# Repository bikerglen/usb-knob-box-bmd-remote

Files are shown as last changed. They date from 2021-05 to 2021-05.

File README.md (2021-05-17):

# usb-knob-box-bmd-remote

Blog post describing this project: https://bikerglen.com/blog/usb-knobs-that-double-as-a-blackmagic-remote/

If using the C# .NET app for testing, the product ID needs to be set to 0x0014 for the EFM8UB@ version or 0x0015 for the PIC18 version. This is inside the file Form1.cs.

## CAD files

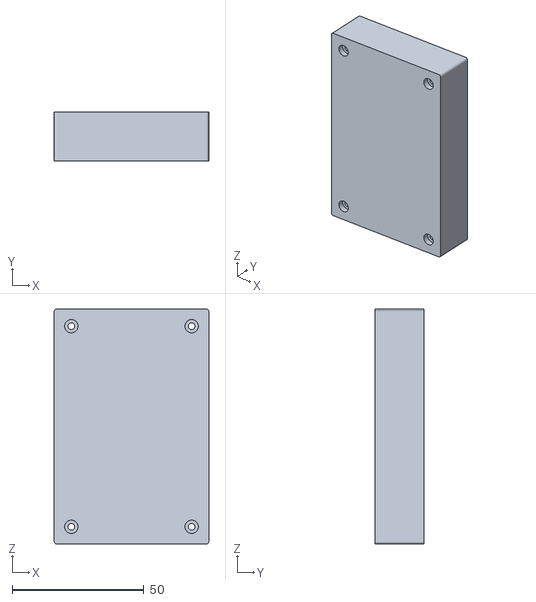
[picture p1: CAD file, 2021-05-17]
enclosure/enclosure-v15-body2.stl
58.8 x 18.5 x 89.3

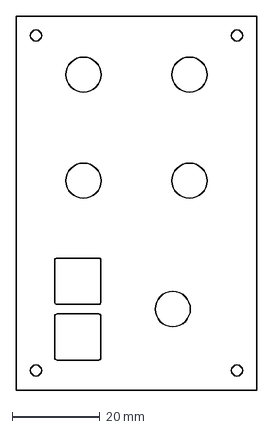
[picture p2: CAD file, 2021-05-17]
panel/knob-box-lid.dxf
54.6 x 85.1 mm

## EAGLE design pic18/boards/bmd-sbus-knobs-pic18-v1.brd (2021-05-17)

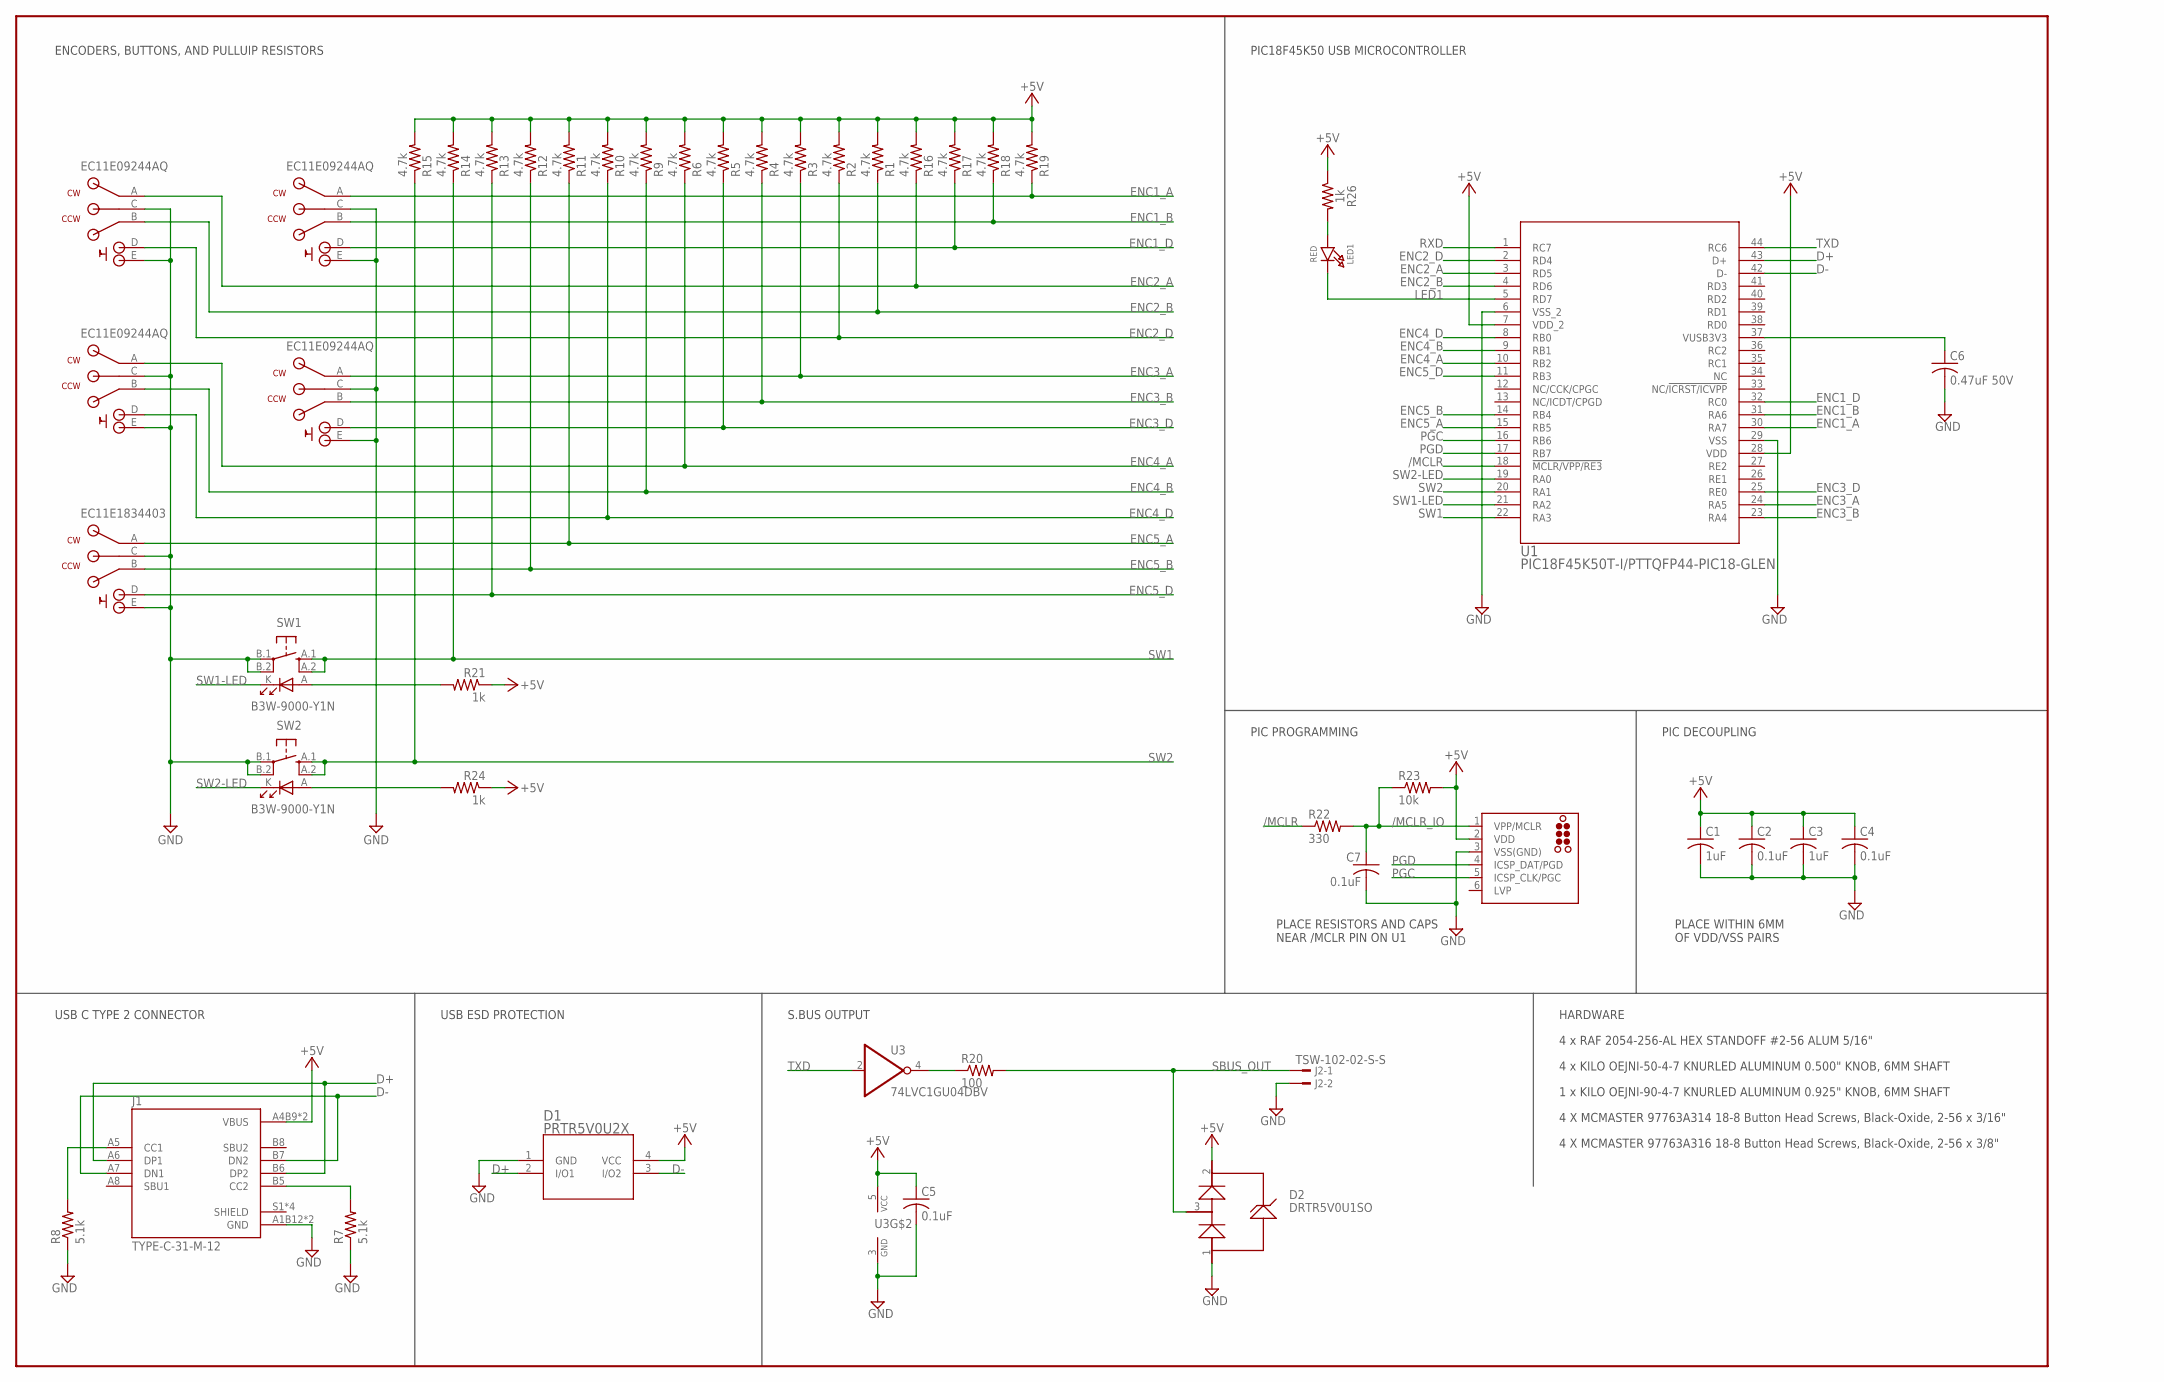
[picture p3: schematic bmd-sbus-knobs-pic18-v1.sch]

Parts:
C1, C3: 1uF; C0603K
C2, C4, C7: 0.1uF; C0603K
C5: 0.1uF; C0603
C6: 0.47uF 50V; C1206K; MFR_PART_NO C1206C474K5RACTU
D1: PRTR5V0U2X; SOT143B
D2: DRTR5V0U1SO; SOT23-3; MFR_PART_NO DRTR5V0U1SO
DEBUG: TC2030-MCP-NL
ENC1, ENC2, ENC3, ENC4, ENC5: EC11E15244B2
J1: TYPE-C-31-M-12; HRO_TYPE-C-31-M-12
J2: TSW-102-02-S-S
LED1: RED; CHIPLED_0805_NOOUTLINE
R1, R2, R3, R4, R5, R6, R9, R10, R11, R12, R13, R14, R15, R16, R17, R18, R19: 4.7k; R0603
R7, R8: 5.1k; R0603
R20: 100; R0603
R21, R24, R26: 1k; R0603
R22: 330; R0603
R23: 10k; R0603
SW1, SW2: B3W-9000-Y1N; OMRON-B3W-ILLUM-BUTTON
U1: PIC18F45K50T-I/PTTQFP44-PIC18-GLEN; TQFP44-PIC18-GLEN
U3: 74LVC1GU04DBV; SOT23-5

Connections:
+5V: C1.1, C2.1, C3.1, C4.1, C5.1, D1.4 (VCC), D2.2, DEBUG.2 (VDD), J1.A4B9 (VBUS), J1.B4A9 (VBUS), R1.2, R2.2, R3.2, R4.2, R5.2, R6.2, R9.2, R10.2, R11.2, R12.2, R13.2, R14.2, R15.2, R16.2, R17.2, R18.2, R19.2, R21.1, R23.2, R24.1, R26.1, U1.7 (VDD_2), U1.28 (VDD), U3.5 (VCC)
/MCLR: R22.1, U1.18 (!MCLR/VPP/RE3)
/MCLR_IO: C7.1, DEBUG.1 (VPP/MCLR), R22.2, R23.1
CC1: J1.A5 (CC1), R8.2
CC2: J1.B5 (CC2), R7.2
D+: D1.2 (I/O1), J1.A6 (DP1), J1.B6 (DP2), U1.43 (D+)
D-: D1.3 (I/O2), J1.A7 (DN1), J1.B7 (DN2), U1.42 (D-)
ENC1_A: ENC1.A, R19.1, U1.30 (RA7)
ENC1_B: ENC1.B, R18.1, U1.31 (RA6)
ENC1_D: ENC1.D, R17.1, U1.32 (RC0)
ENC2_A: ENC2.A, R16.1, U1.3 (RD5)
ENC2_B: ENC2.B, R1.1, U1.4 (RD6)
ENC2_D: ENC2.D, R2.1, U1.2 (RD4)
ENC3_A: ENC3.A, R3.1, U1.24 (RA5)
ENC3_B: ENC3.B, R4.1, U1.23 (RA4)
ENC3_D: ENC3.D, R5.1, U1.25 (RE0)
ENC4_A: ENC4.A, R6.1, U1.10 (RB2)
ENC4_B: ENC4.B, R9.1, U1.9 (RB1)
ENC4_D: ENC4.D, R10.1, U1.8 (RB0)
ENC5_A: ENC5.A, R11.1, U1.15 (RB5)
ENC5_B: ENC5.B, R12.1, U1.14 (RB4)
ENC5_D: ENC5.D, R13.1, U1.11 (RB3)
GND: C1.2, C2.2, C3.2, C4.2, C5.2, C6.2, C7.2, D1.1 (GND), D2.1 (3), DEBUG.3 (VSS(GND)), ENC1.C, ENC1.E, ENC2.C, ENC2.E, ENC3.C, ENC3.E, ENC4.C, ENC4.E, ENC5.C, ENC5.E, J1.A1B12 (GND), J1.B1A12 (GND), J2.2, R7.1, R8.1, SW1.B.1, SW1.B.2, SW2.B.1, SW2.B.2, U1.6 (VSS_2), U1.29 (VSS), U3.3 (GND)
LED1: LED1.C, U1.5 (RD7)
unnamed: R20.1, U3.4 (O)
unnamed: LED1.A, R26.2
unnamed: R21.2, SW1.A
unnamed: R24.2, SW2.A
PGC: DEBUG.5 (ICSP_CLK/PGC), U1.16 (RB6)
PGD: DEBUG.4 (ICSP_DAT/PGD), U1.17 (RB7)
RXD: U1.1 (RC7)
SBUS_OUT: D2.3 (1), J2.1, R20.2
SW1: R14.1, SW1.A.1, SW1.A.2, U1.22 (RA3)
SW1-LED: SW1.K, U1.21 (RA2)
SW2: R15.1, SW2.A.1, SW2.A.2, U1.20 (RA1)
SW2-LED: SW2.K, U1.19 (RA0)
TXD: U1.44 (RC6), U3.2 (I)
VUSB: C6.1, U1.37 (VUSB3V3)

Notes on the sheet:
EC11E09244AQ
EC11E1834403
PIC DECOUPLING
USB C TYPE 2 CONNECTOR
USB ESD PROTECTION
PIC PROGRAMMING
S.BUS OUTPUT
PLACE WITHIN 6MM OF VDD/VSS PAIRS
HARDWARE
4 x RAF 2054-256-AL HEX STANDOFF #2-56 ALUM 5/16"
4 x KILO OEJNI-50-4-7 KNURLED ALUMINUM 0.500" KNOB, 6MM SHAFT
1 x KILO OEJNI-90-4-7 KNURLED ALUMINUM 0.925" KNOB, 6MM SHAFT
4 X MCMASTER 97763A314 18-8 Button Head Screws, Black-Oxide, 2-56 x 3/16"
4 X MCMASTER 97763A316 18-8 Button Head Screws, Black-Oxide, 2-56 x 3/8"
PLACE RESISTORS AND CAPS NEAR /MCLR PIN ON U1
ENCODERS, BUTTONS, AND PULLUIP RESISTORS
PIC18F45K50 USB MICROCONTROLLER

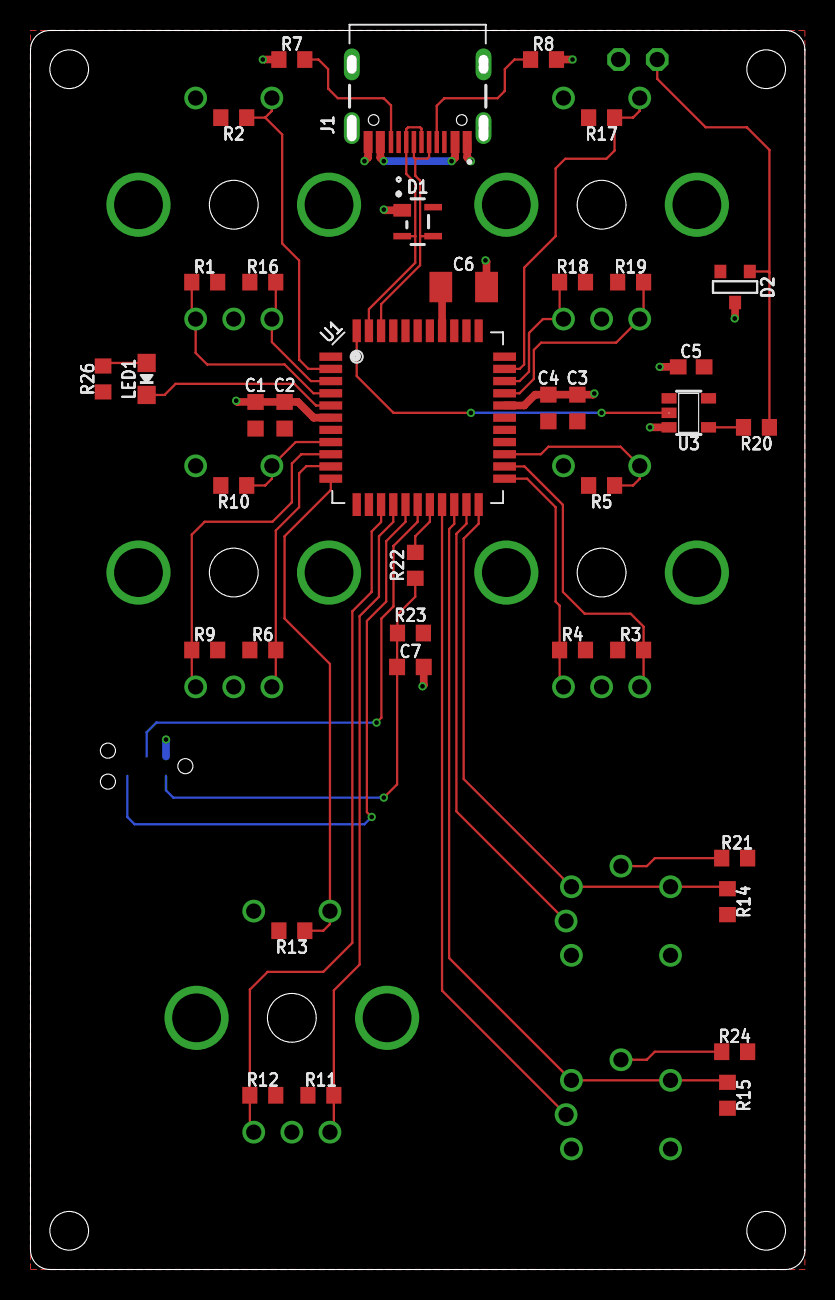
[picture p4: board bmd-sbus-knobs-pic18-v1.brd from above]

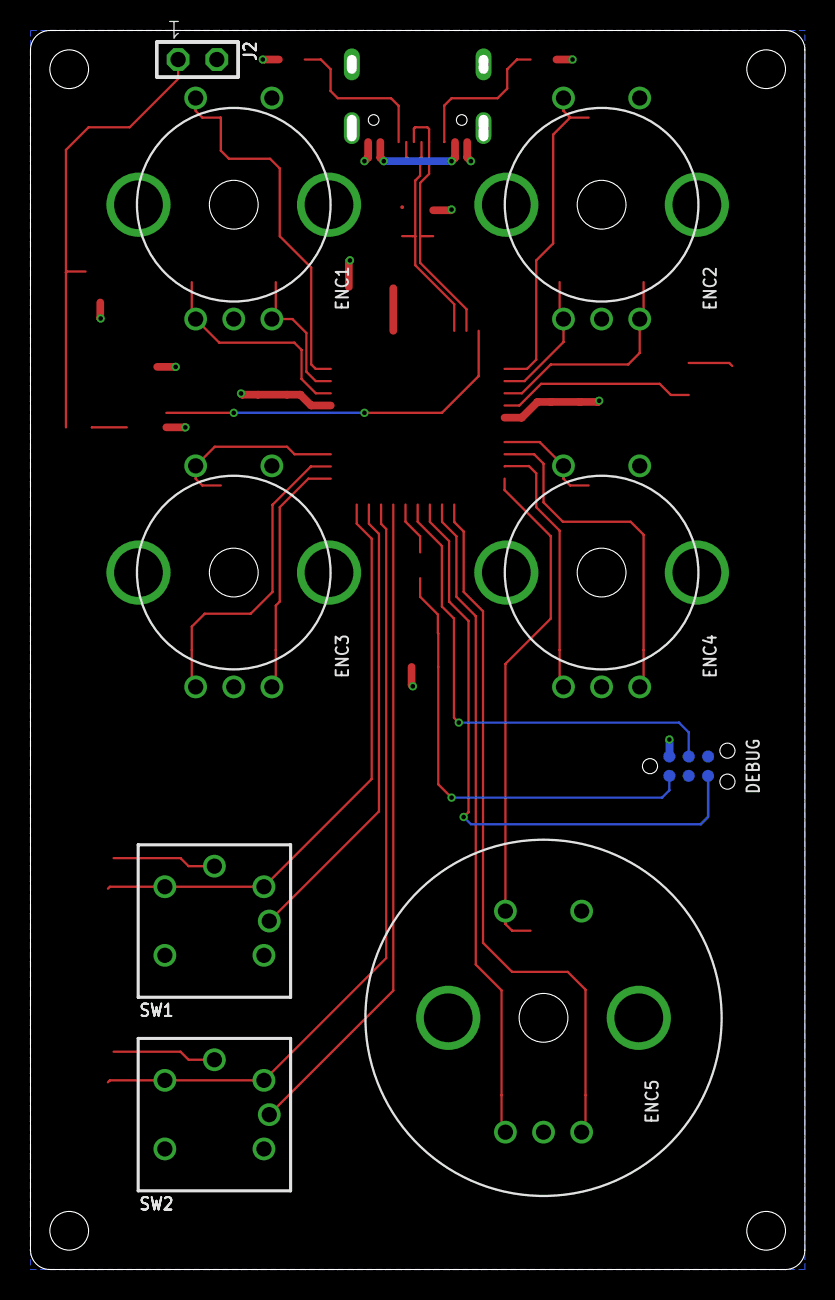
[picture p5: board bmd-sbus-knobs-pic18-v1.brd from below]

Board: 2 copper layers, 50.8 x 81.3 mm, 47 parts (9 on the bottom side), 37 nets.

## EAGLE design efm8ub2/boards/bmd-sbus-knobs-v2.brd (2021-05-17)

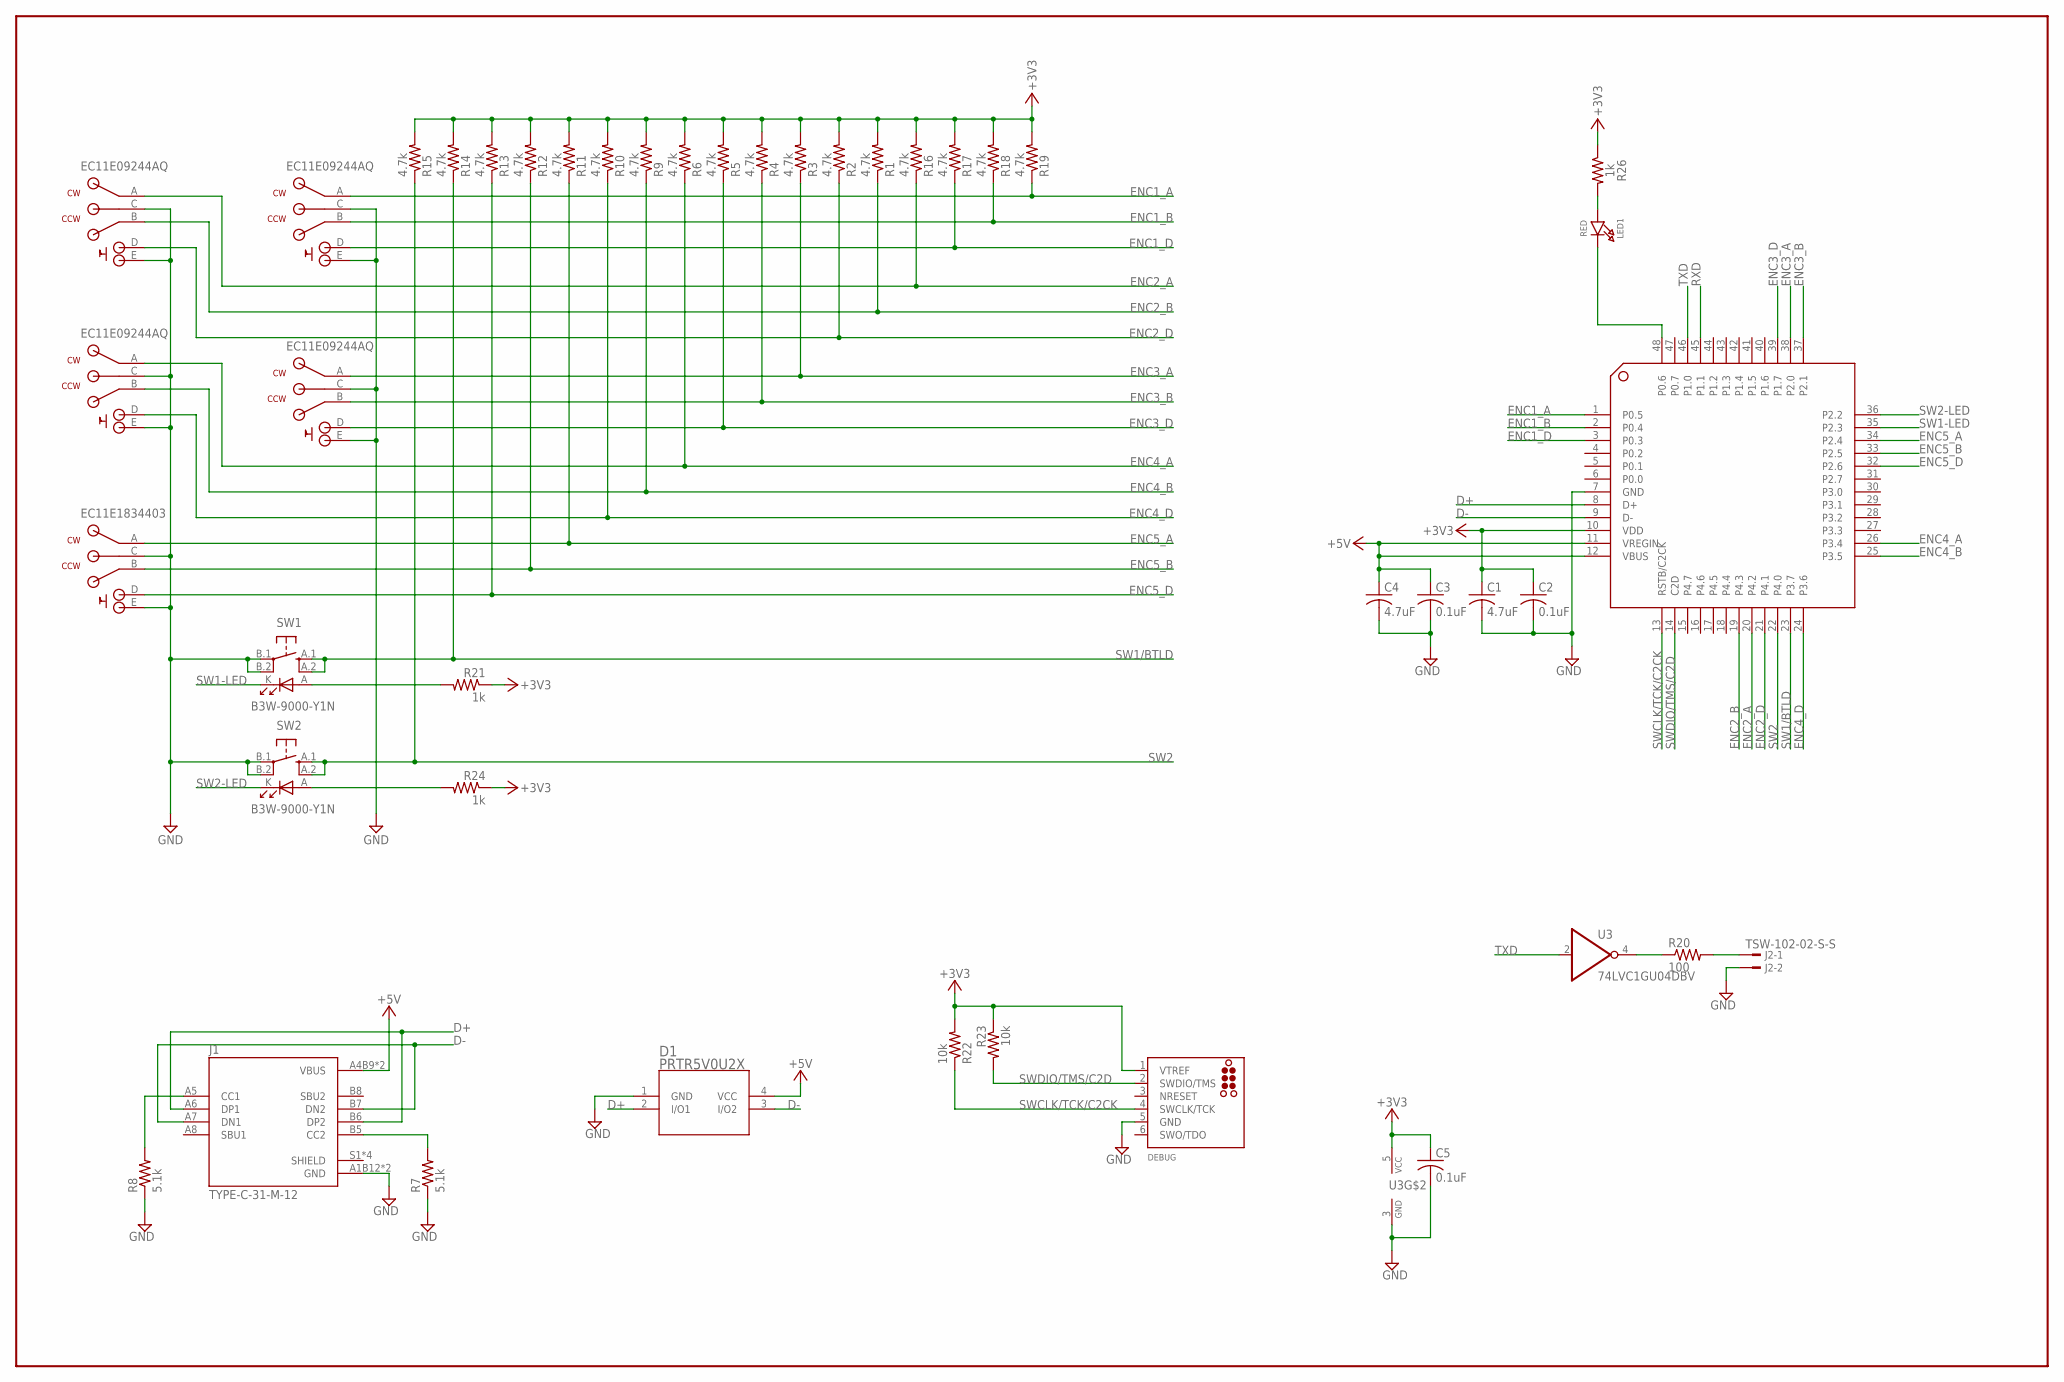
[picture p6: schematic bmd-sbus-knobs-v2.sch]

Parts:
C1, C4: 4.7uF; C0603K
C2, C3: 0.1uF; C0603K
C5: 0.1uF; C0603
D1: PRTR5V0U2X; SOT143B
DEBUG: TC2030-CTX-SWD; TC2030-MCP-NL
ENC1, ENC2, ENC3, ENC4, ENC5: EC11E15244B2
J1: TYPE-C-31-M-12; HRO_TYPE-C-31-M-12
J2: TSW-102-02-S-S
LED1: RED; CHIPLED_0805_NOOUTLINE
R1, R2, R3, R4, R5, R6, R9, R10, R11, R12, R13, R14, R15, R16, R17, R18, R19: 4.7k; R0603
R7, R8: 5.1k; R0603
R20: 100; R0603
R21, R24, R26: 1k; R0603
R22, R23: 10k; R0603
SW1, SW2: B3W-9000-Y1N; OMRON-B3W-ILLUM-BUTTON
U1: EFM8UB20F64G-B-QFP48; EFM8UB2-QFP48
U3: 74LVC1GU04DBV; SOT23-5

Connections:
+3V3: C1.1, C2.1, C5.1, DEBUG.1 (VTREF), R1.2, R2.2, R3.2, R4.2, R5.2, R6.2, R9.2, R10.2, R11.2, R12.2, R13.2, R14.2, R15.2, R16.2, R17.2, R18.2, R19.2, R21.1, R22.2, R23.1, R24.1, R26.1, U1.10 (VDD), U3.5 (VCC)
+5V: C3.1, C4.1, D1.4 (VCC), J1.A4B9 (VBUS), J1.B4A9 (VBUS), U1.11 (VREGIN), U1.12 (VBUS)
D+: D1.2 (I/O1), J1.A6 (DP1), J1.B6 (DP2), U1.8 (D+)
D-: D1.3 (I/O2), J1.A7 (DN1), J1.B7 (DN2), U1.9 (D-)
ENC1_A: ENC1.A, R19.1, U1.1 (P0.5)
ENC1_B: ENC1.B, R18.1, U1.2 (P0.4)
ENC1_D: ENC1.D, R17.1, U1.3 (P0.3)
ENC2_A: ENC2.A, R16.1, U1.20 (P4.2)
ENC2_B: ENC2.B, R1.1, U1.19 (P4.3)
ENC2_D: ENC2.D, R2.1, U1.21 (P4.1)
ENC3_A: ENC3.A, R3.1, U1.38 (P2.0)
ENC3_B: ENC3.B, R4.1, U1.37 (P2.1)
ENC3_D: ENC3.D, R5.1, U1.39 (P1.7)
ENC4_A: ENC4.A, R6.1, U1.26 (P3.4)
ENC4_B: ENC4.B, R9.1, U1.25 (P3.5)
ENC4_D: ENC4.D, R10.1, U1.24 (P3.6)
ENC5_A: ENC5.A, R11.1, U1.34 (P2.4)
ENC5_B: ENC5.B, R12.1, U1.33 (P2.5)
ENC5_D: ENC5.D, R13.1, U1.32 (P2.6)
GND: C1.2, C2.2, C3.2, C4.2, C5.2, D1.1 (GND), DEBUG.5 (GND), ENC1.C, ENC1.E, ENC2.C, ENC2.E, ENC3.C, ENC3.E, ENC4.C, ENC4.E, ENC5.C, ENC5.E, J1.A1B12 (GND), J1.B1A12 (GND), J2.2, R7.1, R8.1, SW1.B.1, SW1.B.2, SW2.B.1, SW2.B.2, U1.7 (GND), U3.3 (GND)
unnamed: J2.1, R20.2
unnamed: R20.1, U3.4 (O)
unnamed: LED1.A, R26.2
unnamed: R21.2, SW1.A
unnamed: R24.2, SW2.A
unnamed: LED1.C, U1.48 (P0.6)
unnamed: J1.B5 (CC2), R7.2
unnamed: J1.A5 (CC1), R8.2
NRESET: DEBUG.3 (NRESET)
RXD: U1.45 (P1.1)
SW1-LED: SW1.K, U1.35 (P2.3)
SW1/BTLD: R14.1, SW1.A.1, SW1.A.2, U1.23 (P3.7)
SW2: R15.1, SW2.A.1, SW2.A.2, U1.22 (P4.0)
SW2-LED: SW2.K, U1.36 (P2.2)
SWCLK/TCK/C2CK: DEBUG.4 (SWCLK/TCK), R22.1, U1.13 (RSTB/C2CK)
SWDIO/TMS/C2D: DEBUG.2 (SWDIO/TMS), R23.2, U1.14 (C2D)
TXD: U1.46 (P1.0), U3.2 (I)

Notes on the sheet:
EC11E09244AQ
EC11E1834403

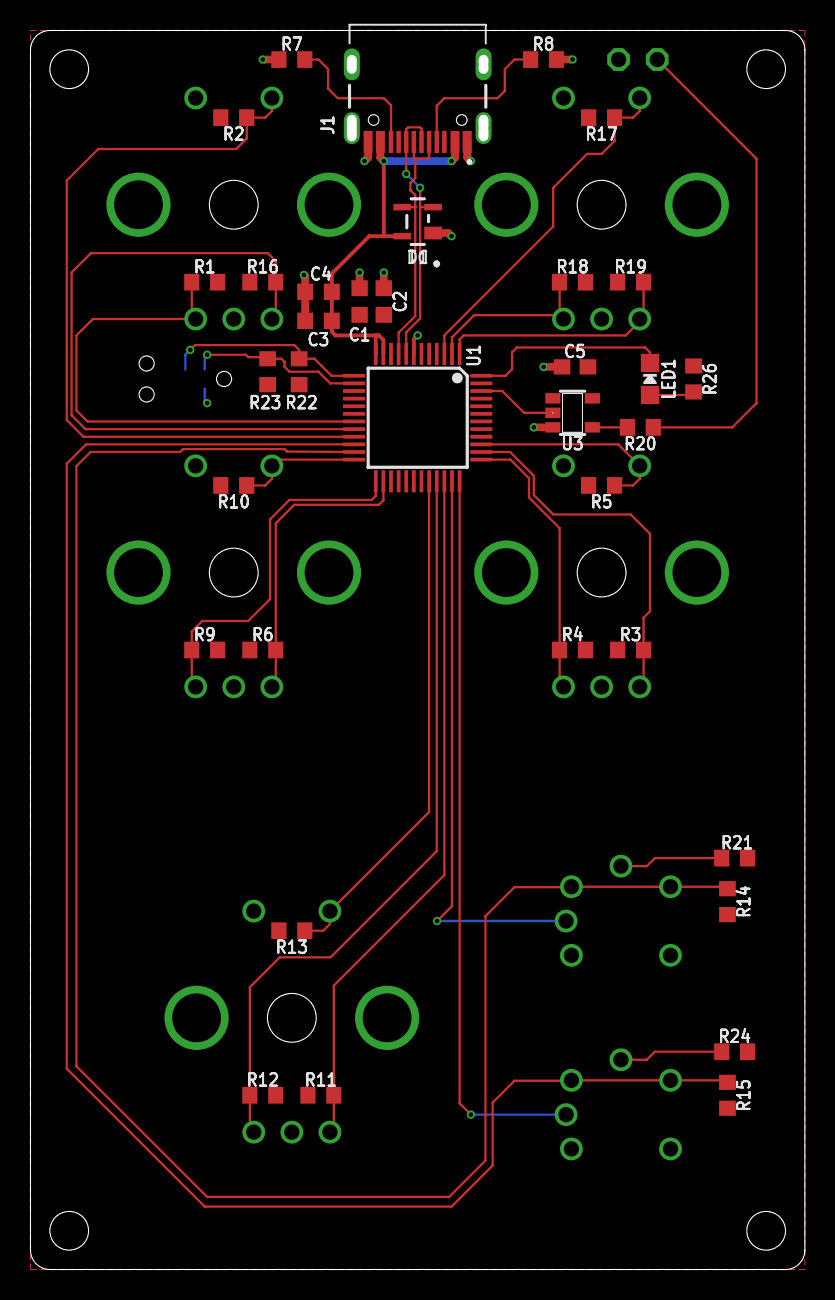
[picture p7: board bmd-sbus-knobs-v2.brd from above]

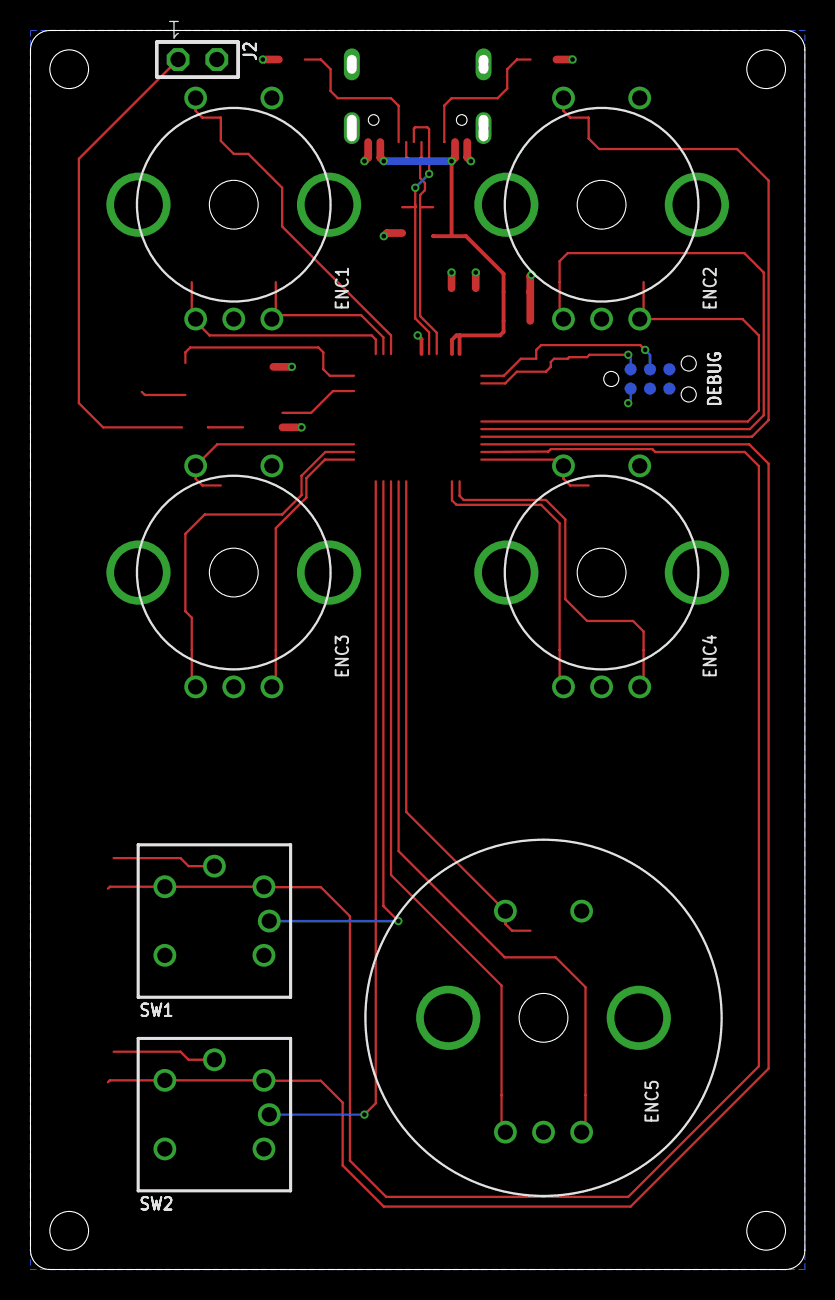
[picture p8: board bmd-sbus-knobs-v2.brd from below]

Board: 2 copper layers, 50.8 x 81.3 mm, 44 parts (9 on the bottom side), 35 nets.

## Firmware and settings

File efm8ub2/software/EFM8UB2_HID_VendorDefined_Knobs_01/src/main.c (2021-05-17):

//-----------------------------------------------------------------------------------------------
// EFM8UB2 USB Controller Software for Sony BKS-R3209 Panels
//

//-----------------------------------------------------------------------------------------------
// includes
//

#include "SI_EFM8UB2_Register_Enums.h"
#include "efm8_usb.h"
#include "descriptors.h"
#include "idle.h"
#include "InitDevice.h"
#include "config.h"


//-----------------------------------------------------------------------------------------------
// defines
//

// device pins
SI_SBIT(SW1_LED,  SFR_P2, 3); // SW1 LED -- top button on top of board
SI_SBIT(SW2_LED,  SFR_P2, 2); // SW2 LED -- bottom button on top of board
SI_SBIT(USER_LED, SFR_P0, 6); // USER LED -- on bottom of board

#define ENC1_A  ((P0 & 0x20) ? 1 : 0)
#define ENC1_B  ((P0 & 0x10) ? 1 : 0)
#define ENC1_SW ((P0 & 0x08) ? 0 : 1)

#define ENC2_A  ((P4 & 0x04) ? 1 : 0)
#define ENC2_B  ((P4 & 0x08) ? 1 : 0)
#define ENC2_SW ((P4 & 0x02) ? 0 : 1)

#define ENC3_A  ((P2 & 0x01) ? 1 : 0)
#define ENC3_B  ((P2 & 0x02) ? 1 : 0)
#define ENC3_SW ((P1 & 0x80) ? 0 : 1)

#define ENC4_A  ((P3 & 0x10) ? 1 : 0)
#define ENC4_B  ((P3 & 0x20) ? 1 : 0)
#define ENC4_SW ((P3 & 0x40) ? 0 : 1)

#define ENC5_A  ((P2 & 0x10) ? 1 : 0)
#define ENC5_B  ((P2 & 0x20) ? 1 : 0)
#define ENC5_SW ((P2 & 0x40) ? 0 : 1)

#define SW1     ((P3 & 0x80) ? 0 : 1)
#define SW2     ((P4 & 0x01) ? 0 : 1)

#define LED_ON  0
#define LED_OFF 1

#define SYSCLK       48000000      // SYSCLK frequency in Hz

#define IRIS_CHANNEL          1
#define FOCUS_CHANNEL         2
#define AUTOFOCUS_CHANNEL     3
#define GAIN_CHANNEL          5
#define SHUTTER_CHANNEL       6
#define WHITE_BALANCE_CHANNEL 7


//-----------------------------------------------------------------------------------------------
// typedefs
//

typedef uint8_t FSTOP_TABLE[25];


//-----------------------------------------------------------------------------------------------
// prototypes
//

void Timer2_Init (int counts);
uint16_t lfsr (void);
uint8_t GetDirection (uint8_t a, uint8_t b);
uint8_t ProcessButton (uint8_t which, uint8_t sw);
void ConvertServoChannelsToSbusData (void);


//-----------------------------------------------------------------------------------------------
// globals
//

SI_SEGMENT_VARIABLE(fstops, const FSTOP_TABLE, SI_SEG_CODE) = {
	212, 205, 198, 191, 184,
	177, 170, 163, 156, 149,
	142, 135, 128, 121, 115,
	107, 100,  93,  86,  80,
     73,  66,  60,  56,  44
};

// signals from ISRs to main loop
volatile uint8_t flag250 = 0;

// pseudo random lfsr state
uint16_t lfsr_state = 0x0001;

uint8_t enc1a;
uint8_t enc1b;
uint8_t enc2a;
uint8_t enc2b;
uint8_t enc3a;
uint8_t enc3b;
uint8_t enc4a;
uint8_t enc4b;
uint8_t enc5a;
uint8_t enc5b;

// local variables for making aUSB report
uint8_t xdata reportNeeded;
uint8_t xdata thisUsbReportData[6];
uint8_t lastUsbReportData0 = 0;

// variables used to communicate report to USB ISR
volatile uint8_t xdata usbReportNeeded = false;
volatile uint8_t xdata usbReportData[6];

uint8_t xdata buttonStates[8];

// camera parameters
int8_t xdata balance;
int8_t xdata gain;
int8_t xdata shutter;
uint8_t xdata iris;
uint8_t xdata focus;

// servo data sending phase
uint8_t xdata servoPhase;

// servo channels
uint16_t xdata servoChannels[18];

// sbus data
uint8_t txByte;
uint8_t xdata sbusData[25];


//-----------------------------------------------------------------------------------------------
// SiLabs_Startup() Routine
//

void SiLabs_Startup (void)
{
  // Disable the watchdog here
}
 

//-----------------------------------------------------------------------------------------------
// main() Routine
//

int16_t main(void)
{
	uint8_t SFRPAGE_save;
	uint8_t led_timer = 0;
    uint8_t newUsbState = 0;
    uint8_t oldUsbState = 0;
    uint8_t i;

    // set default pin and peripheral configuration
    enter_DefaultMode_from_RESET();

	// Init Timer2 to generate interrupts at 250 Hz
	Timer2_Init (16000); // SYSCLK / 12 / 250

	// initialize encoder 3-bit states to prevent spurious up/down signals at startup
	enc1a = ENC1_A ? 7 : 0;
	enc1b = ENC1_B ? 7 : 0;
	enc2a = ENC2_A ? 7 : 0;
	enc2b = ENC2_B ? 7 : 0;
	enc3a = ENC3_A ? 7 : 0;
	enc3b = ENC3_B ? 7 : 0;
	enc4a = ENC4_A ? 7 : 0;
	enc4b = ENC4_B ? 7 : 0;
	enc5a = ENC5_A ? 7 : 0;
	enc5b = ENC5_B ? 7 : 0;

	// zero button states
	for (i = 0; i < 8; i++) {
		buttonStates[i] = 0;
	}

	// turn off leds
	SW1_LED = LED_OFF;
	SW2_LED = LED_OFF;

	// initialize camera parameters
	balance = 0;
	gain = 0;
	shutter = 0;
	iris = 0;
	focus = 128;

	// initialize servo phase
	servoPhase = 0;

	// initialize servo channels
	for (i = 0; i < 18; i++) {
		servoChannels[i] = 0x400;
	}

	// initialize sbus data
	for (i = 0; i < 25; i++) {
		sbusData[i] = 0x00;
	}

	// loop forever
	while (1)
	{
		// check if 100 Hz timer expired
		if (flag250) {
			flag250 = false;

			// new USB state
			newUsbState = USBD_GetUsbState ();

			// blink LED based on USB state
			if (newUsbState == USBD_STATE_CONFIGURED) {
				// run one led pattern for configured usb state
				if (led_timer < 25) {
					USER_LED = LED_ON; // LED ON
				} else if (led_timer < 50) {
					USER_LED = LED_OFF; // LED OFF
				} else if (led_timer < 75) {
					USER_LED = LED_ON; // LED ON
				} else if (led_timer < 100) {
					USER_LED = LED_OFF; // LED OFF
				}

				// tasks to run on entering configured state
				if (newUsbState != oldUsbState) {
					oldUsbState = newUsbState;
					// TODO
				}
			} else {
				// and another for all other usb states
				if (led_timer < 50) {
					USER_LED = LED_ON; // LED ON
				} else {
					USER_LED = LED_OFF; // LED OFF
				}

				// tasks to run on leaving configured state
				if ((newUsbState != oldUsbState) && (oldUsbState == USBD_STATE_CONFIGURED)) {
					oldUsbState = newUsbState;
					// TODO
				}
			}

			// update led timer
			if (++led_timer == 100) {
				led_timer = 0;
			}

			// sample encoders
			enc1a = ((enc1a << 1) | ENC1_A) & 7;
			enc1b = ((enc1b << 1) | ENC1_B) & 7;
			enc2a = ((enc2a << 1) | ENC2_A) & 7;
			enc2b = ((enc2b << 1) | ENC2_B) & 7;
			enc3a = ((enc3a << 1) | ENC3_A) & 7;
			enc3b = ((enc3b << 1) | ENC3_B) & 7;
			enc4a = ((enc4a << 1) | ENC4_A) & 7;
			enc4b = ((enc4b << 1) | ENC4_B) & 7;
			enc5a = ((enc5a << 1) | ENC5_A) & 7;
			enc5b = ((enc5b << 1) | ENC5_B) & 7;

			// clear USB report data
			for (i = 0; i < 6; i++) {
				thisUsbReportData[i] = 0;
			}

			// sample and process buttons
			thisUsbReportData[0] |= ProcessButton (0, ENC1_SW);
			thisUsbReportData[0] |= ProcessButton (1, ENC2_SW);
			thisUsbReportData[0] |= ProcessButton (2, ENC3_SW);
			thisUsbReportData[0] |= ProcessButton (3, ENC4_SW);
			thisUsbReportData[0] |= ProcessButton (4, ENC5_SW);
			thisUsbReportData[0] |= ProcessButton (5, SW1);
			thisUsbReportData[0] |= ProcessButton (6, SW2);

			// process encoders
			thisUsbReportData[1] = GetDirection (enc1a, enc1b);
			thisUsbReportData[2] = GetDirection (enc2a, enc2b);
			thisUsbReportData[3] = GetDirection (enc3a, enc3b);
			thisUsbReportData[4] = GetDirection (enc4a, enc4b);
			thisUsbReportData[5] = GetDirection (enc5a, enc5b);

			// check if report needed
			reportNeeded = thisUsbReportData[1] | thisUsbReportData[2] | thisUsbReportData[3] | thisUsbReportData[4] | thisUsbReportData[5] |
					(thisUsbReportData[0] != lastUsbReportData0);

			// save key presses for the next time around
			lastUsbReportData0 = thisUsbReportData[0];

			// send report to IRQ-based USB code safely
			if (reportNeeded) {
				SFRPAGE_save = SFRPAGE;
				USB_DisableInts ();
				SFRPAGE = SFRPAGE_save;

				usbReportNeeded = true;
				for (i = 0; i < 6; i++) {
					usbReportData[i] = thisUsbReportData[i];
				}

				SFRPAGE_save = SFRPAGE;
				USB_EnableInts ();
				SFRPAGE = SFRPAGE_save;
			}

			// white balance is controlled by encoder 1
			if (thisUsbReportData[1] & 0x01) {
				balance++;
			} else if (thisUsbReportData[1] & 0x02) {
				balance--;
			}

			// gain -- encoder 2
			if (thisUsbReportData[2] & 0x01) {
				gain++;
			} else if (thisUsbReportData[2] & 0x02) {
				gain--;
			}

			// shutter -- encoder 3
			if (thisUsbReportData[3] & 0x01) {
				shutter++;
			} else if (thisUsbReportData[3] & 0x02) {
				shutter--;
			}

			// iris -- encoder 4
			if (thisUsbReportData[4] & 0x01) {
				if (iris < 24) iris++;
			} else if (thisUsbReportData[4] & 0x02) {
				if (iris > 0) iris--;
			}

			// focus is controlled by encoder 5
			if (thisUsbReportData[5] & 0x01) {
				// CW = focus farther away
				if (focus > 44) focus--;
			} else if (thisUsbReportData[5] & 0x02) {
				// CCW = focus closer
				if (focus < 212) focus++;
			}

			// push to auto focus -- encoder 5 knob
			// TODO

			if (servoPhase == 0) {
				// convert user actions / camera parameters to servo channel data

				// white balance
				if (servoChannels[WHITE_BALANCE_CHANNEL] == 0x400) {
					if (balance > 0) {
						balance--;
						servoChannels[WHITE_BALANCE_CHANNEL] = 8*212; // stick up
					} else if (balance < 0) {
						balance++;
						servoChannels[WHITE_BALANCE_CHANNEL] = 8*44;  // stick down
					}
				} else {
					servoChannels[WHITE_BALANCE_CHANNEL] = 0x400;     // back to stick neutral
				}

				// gain
				if (servoChannels[GAIN_CHANNEL] == 0x400) {
					if (gain > 0) {
						gain--;
						servoChannels[GAIN_CHANNEL] = 8*212; // stick up
					} else if (gain < 0) {
						gain++;
						servoChannels[GAIN_CHANNEL] = 8*44;  // stick down
					}
				} else {
					servoChannels[GAIN_CHANNEL] = 0x400;     // back to stick neutral
				}

				// shutter
				if (servoChannels[SHUTTER_CHANNEL] == 0x400) {
					if (shutter > 0) {
						shutter--;
						servoChannels[SHUTTER_CHANNEL] = 8*212; // stick up
					} else if (shutter < 0) {
						shutter++;
						servoChannels[SHUTTER_CHANNEL] = 8*44;  // stick down
					}
				} else {
					servoChannels[SHUTTER_CHANNEL] = 0x400;     // back to stick neutral
				}

				// iris
				servoChannels[IRIS_CHANNEL] = fstops[iris] << 3;

				// focus
				servoChannels[FOCUS_CHANNEL] = focus << 3;

			} else if (servoPhase == 1) {
				// convert servo channels to sbus data
				ConvertServoChannelsToSbusData ();
			} else if (servoPhase == 2) {
				// send sbus data to camera
				txByte = 0;
				SCON1 |= SCON1_TI__BMASK;
			}

			if (++servoPhase >= 3) {
				servoPhase = 0;
			}

		} // end if (flag250)
	}
}


void Timer2_Init (int counts)
{
   TMR2CN0 = 0x00;                     // Stop Timer2; Clear TF2;
                                       // use SYSCLK/12 as timebase
   CKCON0 &= ~0x60;                    // Timer2 clocked based on T2XCLK;

   TMR2RL = -counts;                   // Init reload values
   TMR2 = 0xffff;                      // Set to reload immediately
   IE_ET2 = 1;                         // Enable Timer2 interrupts
   TMR2CN0_TR2 = 1;                    // Start Timer2
}


SI_INTERRUPT(TIMER2_ISR, TIMER2_IRQn)
{
    TMR2CN0_TF2H = 0;                   // Clear Timer2 interrupt flag
	flag250 = 1;
}


uint16_t lfsr (void)
{
    uint16_t newbit;

    newbit = ((lfsr_state >> 0) ^ (lfsr_state >> 2) ^ (lfsr_state >> 3) ^ (lfsr_state >> 5)) /* & 1u */;
    lfsr_state = (lfsr_state >> 1) | (newbit << 15);

    return lfsr_state;
}


uint8_t GetDirection (uint8_t a, uint8_t b)
{
	if (a == 4) {
		// 100 => falling edge
		return (b & 2) ? 0x01 : 0x02; // 0x01 = cw, 0x02 = ccw
	} else if (a == 3) {
		// 011 => rising edge
		return (b & 2) ? 0x02 : 0x01; // 0x02 = ccw, 0x01 = cw
	}

	return 0;
}


uint8_t ProcessButton (uint8_t which, uint8_t sw)
{
	uint8_t state;

	state = buttonStates[which];

	switch (state) {
		case 0: state = sw ? 1 : 0; break;
		case 1: state = sw ? 2 : 0; break;
		case 2: state = sw ? 2 : 3; break;
		case 3: state = sw ? 2 : 0; break;
	}

	buttonStates[which] = state;

	return (state & 2) ? (1 << which) : 0;
}


void ConvertServoChannelsToSbusData (void)
{
    uint8_t i, byte_in_sbus, bit_in_sbus, bit_in_servo, ch;

    // clear sbus data array
    for (i = 0; i < 25; i++)
    {
        sbusData[i] = 0;
    }

    // start code, flags, and end code
    sbusData[0] = 0x0F;
    sbusData[23] = 0x00;
    sbusData[24] = 0x00;

    //reset counters
    ch = 0;
    bit_in_servo = 0;
    byte_in_sbus = 1;
    bit_in_sbus = 0;

    for (i = 0; i < 176; i++)
    {
        if ((servoChannels[ch] & (1 << bit_in_servo)) != 0)
        {
            sbusData[byte_in_sbus] |= (1 << bit_in_sbus);
        }

        bit_in_sbus++;
        bit_in_servo++;

        if (bit_in_sbus == 8)
        {
            bit_in_sbus = 0;
            byte_in_sbus++;
        }

        if (bit_in_servo == 11)
        {
            bit_in_servo = 0;
            ch++;
        }
    }
}


SI_INTERRUPT(UART1_ISR, UART1_IRQn)
{
	if (SCON1 & SCON1_TI__BMASK) {
		SCON1 &= ~SCON1_TI__BMASK;
		if (txByte < 25) {
			SBUF1 = sbusData[txByte++];
		}
	}

	if (SCON1 & SCON1_RI__BMASK) {
		SCON1 &= ~SCON1_RI__BMASK;
	}
}

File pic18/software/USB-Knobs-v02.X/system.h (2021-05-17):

/*******************************************************************************
Copyright 2016 Microchip Technology Inc. (www.microchip.com)

Licensed under the Apache License, Version 2.0 (the "License");
you may not use this file except in compliance with the License.
You may obtain a copy of the License at

    http://www.apache.org/licenses/LICENSE-2.0

Unless required by applicable law or agreed to in writing, software
distributed under the License is distributed on an "AS IS" BASIS,
WITHOUT WARRANTIES OR CONDITIONS OF ANY KIND, either express or implied.
See the License for the specific language governing permissions and
limitations under the License.

To request to license the code under the MLA license (www.microchip.com/mla_license), 
please contact mla_licensing@microchip.com
*******************************************************************************/

#ifndef SYSTEM_H
#define SYSTEM_H

#include <xc.h>
#include <stdbool.h>

#include "fixed_address_memory.h"

#define MAIN_RETURN void

// 250 Hz timer 0 load / reload value
// dec2hex(65535-12e6/16/250) = 0xF447
// #define TMR0_RELOAD_VALUE 0xF447

// 8333 Hz timer 0 load / reload value
// dec2hex(round(65535-12e6/16/8333)) = 0xFFA5
#define TMR0_RELOAD_VALUE 0xFFA5

// 250 Hz timer 2 period value
// dec2hex(12e6/16/12/250-1)
#define TMR2_PERIOD 0xF9

// GPIO input pins
#define ENC1_A   (PORTAbits.RA7 ? 1 : 0)
#define ENC1_B   (PORTAbits.RA6 ? 1 : 0)
#define ENC1_SW  (PORTCbits.RC0 ? 0 : 1)
#define ENC2_A   (PORTDbits.RD5 ? 1 : 0)
#define ENC2_B   (PORTDbits.RD6 ? 1 : 0)
#define ENC2_SW  (PORTDbits.RD4 ? 0 : 1)
#define ENC3_A   (PORTAbits.RA5 ? 1 : 0)
#define ENC3_B   (PORTAbits.RA4 ? 1 : 0)
#define ENC3_SW  (PORTEbits.RE0 ? 0 : 1)
#define ENC4_A   (PORTBbits.RB2 ? 1 : 0)
#define ENC4_B   (PORTBbits.RB1 ? 1 : 0)
#define ENC4_SW  (PORTBbits.RB0 ? 0 : 1)
#define ENC5_A   (PORTBbits.RB5 ? 1 : 0)
#define ENC5_B   (PORTBbits.RB4 ? 1 : 0)
#define ENC5_SW  (PORTBbits.RB3 ? 0 : 1)
#define SW1      (PORTAbits.RA3 ? 0 : 1)
#define SW2      (PORTAbits.RA1 ? 0 : 1)

// GPIO output pins
#define USER_LED LATDbits.LATD7
#define SW1_LED  LATAbits.LATA2
#define SW2_LED  LATAbits.LATA0

// led states
#define LED_ON   0
#define LED_OFF  1


/*** System States **************************************************/
typedef enum {
    SYSTEM_STATE_USB_START,
    SYSTEM_STATE_USB_SUSPEND,
    SYSTEM_STATE_USB_RESUME
} SYSTEM_STATE;

/*********************************************************************
* Function: void SYSTEM_Initialize( SYSTEM_STATE state )
*
* Overview: Initializes the system.
*
* PreCondition: None
*
* Input:  SYSTEM_STATE - the state to initialize the system into
*
* Output: None
*
********************************************************************/
void SYSTEM_Initialize( SYSTEM_STATE state );


/*********************************************************************
* Function: void SYSTEM_Tasks(void)
*
* Overview: Runs system level tasks that keep the system running
*
* PreCondition: System has been initalized with SYSTEM_Initialize()
*
* Input: None
*
* Output: None
*
********************************************************************/
//void SYSTEM_Tasks(void);
#define SYSTEM_Tasks()

void TMR0_Initialize (void);
void TMR0_InterruptHandler (void);

void TMR2_Initialize (void);
void TMR2_InterruptHandler (void);

#endif //SYSTEM_H

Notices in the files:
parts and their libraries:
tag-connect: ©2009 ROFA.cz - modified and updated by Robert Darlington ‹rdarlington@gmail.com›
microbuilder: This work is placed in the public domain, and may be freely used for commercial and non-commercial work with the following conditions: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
